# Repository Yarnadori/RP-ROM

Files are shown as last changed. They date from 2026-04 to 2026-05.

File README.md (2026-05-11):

# RP-ROM

M27C256 EPROM エミュレータ。RP2354A (RP2350 QFN-60) を搭載した自作 PCB で、32KB の ROM コンテンツを USB 経由で書き込み・読み出しできる。

## 概要

| 項目 | 内容 |
| --- | --- |
| 対象 EPROM | M27C256 互換 (32KB, 15-bit address, 8-bit data) |
| MCU | RP2354A (RP2350 QFN-60, 360 MHz 動作) |
| インターフェース | USB-C (CDC Serial) |
| フラッシュ保持 | 電源断後も ROM データを内蔵フラッシュに保存 |

## リポジトリ構成

```text
RP-ROM/
├── hardware/          # KiCad プロジェクト (回路図・PCB)
│   └── production/    # 製造用ファイル (BOM, Gerber, 部品配置)
├── software/          # RP2350 ファームウェア (C / Pico SDK)
│   └── main.c
└── tools/             # ホスト側 Python ツール
    └── rom_tool.py
```

## ハードウェア

KiCad で設計。製造 BOM の概要:

| Ref | 数量 | 部品 / 値 | パッケージ / 備考 | LCSC Part # |
| --- | ---: | --- | --- | --- |
| IC1 | 1 | RP2354A | QFN-60, メイン MCU | C41378174 |
| U1 | 1 | RT9080-33GJ5 | TSOT-23-5, 3.3V LDO | C7528830 |
| J1 | 1 | USB_C_Receptacle_USB2.0_16P | USB-C | C2843970 |
| J2, J3 | 2 | Conn_01x14_Pin | 1×14 ピンヘッダ | |
| J4 | 1 | Conn_01x03 | JST SH 3P, デバッガー | C7430452 |
| SW1 | 1 | SW_Push | TS-1088 系タクトスイッチ | C720477 |
| Y1 | 1 | 12 MHz | 3225 4-pin 水晶 | C9002 |
| L1 | 1 | 3.3uH | AOTA-B201610S3R3-101-T | C42411119 |
| D1, D2 | 2 | RB521S-30 | SOD-523 ショットキーダイオード | C8523 |
| D3 | 1 | LED | 0402 | C51933305 |
| C1 | 1 | 4.7nF | 0402 | C1538 |
| C2, C3 | 2 | 1uF | 0402 | C52923 |
| C5, C8 | 2 | 15pF | 0402 | C1548 |
| C9, C10, C11 | 3 | 4.7uF | 0402 | C23733 |
| C4, C6, C7, C12-C14 | 6 | 0.1uF | 0402 | C1525 |
| R1 | 1 | 1MΩ | 0402 | C26083 |
| R2, R3 | 2 | 5.1kΩ | 0402 | C25905 |
| R4, R5, R6 | 3 | 1k | 0402 | C11702 |
| R7, R8 | 2 | 27Ω | 0402 | C25100 |
| R9 | 1 | 33Ω | 0402 | C25105 |

製造ファイルは `hardware/production/` に格納。

## ファームウェア

### 必要環境

- [Raspberry Pi Pico SDK](https://github.com/raspberrypi/pico-sdk) v2.2.0

### 動作

- **Core 1**: ROM アドレス線監視・データ出力 (フラッシュ不使用のタイトループ、360 MHz)
- **Core 0**: USB シリアル経由のコマンド処理
- **永続化**: 書き込んだ ROM データを内蔵フラッシュ末尾 36KB に保存。電源投入時に自動ロード。

## ツール (tools/)

Python 製のホストツール。詳細は [tools/README.md](tools/README.md) を参照。

```bash
cd tools
uv run rom_tool.py write COM3 firmware.hex
uv run rom_tool.py read  COM3 dump.bin
uv run rom_tool.py verify COM3 firmware.hex
uv run rom_tool.py erase COM3
uv run rom_tool.py info  COM3
```

対応フォーマット: `.bin` / Intel HEX (`.hex`)

## ライセンス

[MIT License](LICENSE)

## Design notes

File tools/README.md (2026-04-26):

# RP-ROM Tools

RP-ROM EPROM エミュレータ用ホストツール。USB シリアル (CDC) 経由で ROM データの書き込み・読み出し・検証を行う。

## セットアップ

[uv](https://github.com/astral-sh/uv) を使用:

```bash
cd tools
uv sync
```

または pip:

```bash
pip install pyserial
```

## 使い方

```text
python rom_tool.py <command> <COMx> [file]
```

### コマンド一覧

| コマンド | 説明 |
| --- | --- |
| `write <port> <file>` | ROM イメージをデバイスに書き込む |
| `read <port> <file>` | デバイスから ROM イメージを読み出す |
| `verify <port> <file>` | デバイス内容をファイルと照合する |
| `erase <port>` | ROM を消去する (全バイト 0xFF) |
| `info <port>` | デバイス情報を表示する |

### 例

```bash
# .hex または .bin の書き込み
uv run rom_tool.py write COM3 firmware.hex
uv run rom_tool.py write COM3 firmware.bin

# 読み出し
uv run rom_tool.py read COM3 dump.bin
uv run rom_tool.py read COM3 dump.hex

# 書き込み後の検証
uv run rom_tool.py verify COM3 firmware.hex

# 消去
uv run rom_tool.py erase COM3

# デバイス情報
uv run rom_tool.py info COM3
```

## 対応ファイル形式

| 拡張子 | 形式 |
| --- | --- |
| `.hex` | Intel HEX |
| `.bin` / `.rom` / `.epr` | バイナリ |
| その他 | 先頭バイトで自動判別 |

ROM サイズ (32KB) に満たないバイナリは 0xFF でパディングされる。

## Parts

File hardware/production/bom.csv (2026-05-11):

Designator | Footprint | Quantity | Value | LCSC Part #
C1 | 0402 | 1 | 4.7nF | C1538
C10, C11, C9 | 0402 | 3 | 4.7u | C23733
C12, C13, C14, C4, C6, C7 | 0402 | 6 | 0.1u | C1525
C2, C3 | 0402 | 2 | 1uF | C52923
C5, C8 | 0402 | 2 | 15p | C1548
D1, D2 | D_SOD-523 | 2 | RB521S-30 | C8523
D3 | 0402 | 1 | LED | C51933305
IC1 | QFN-60-1EP_7x7mm_P0.4mm_EP3.4x3.4mm_ThermalVias | 1 | RP2354A | C41378174
J1 | USB_C_Receptacle_G-Switch_GT-USB-7051x | 1 | USB_C_Receptacle_USB2.0_16P | C2843970
J2, J3 | PinHeader_1x14_P2.54mm_Vertical | 2 | Conn_01x14_Pin
J4 | JST_SH_BM03B-SRSS-TB_1x03-1MP_P1.00mm_Vertical | 1 | Conn_01x03 | C7430452
L1 | AOTA-B201610S3R3-101-T | 1 | 3.3u | C42411119
R1 | 0402 | 1 | 1MΩ | C26083
R2, R3 | 0402 | 2 | 5.1kΩ | C25905
R4, R5, R6 | 0402 | 3 | 1k | C11702
R7, R8 | 0402 | 2 | 27 | C25100
R9 | 0402 | 1 | 33 | C25105
SW1 | SW_SPST_TS-1088-xR020 | 1 | SW_Push | C720477
U1 | TSOT-23-5 | 1 | RT9080-33GJ5 | C7528830
Y1 | Crystal_SMD_3225-4Pin_3.2x2.5mm | 1 | 12m | C9002

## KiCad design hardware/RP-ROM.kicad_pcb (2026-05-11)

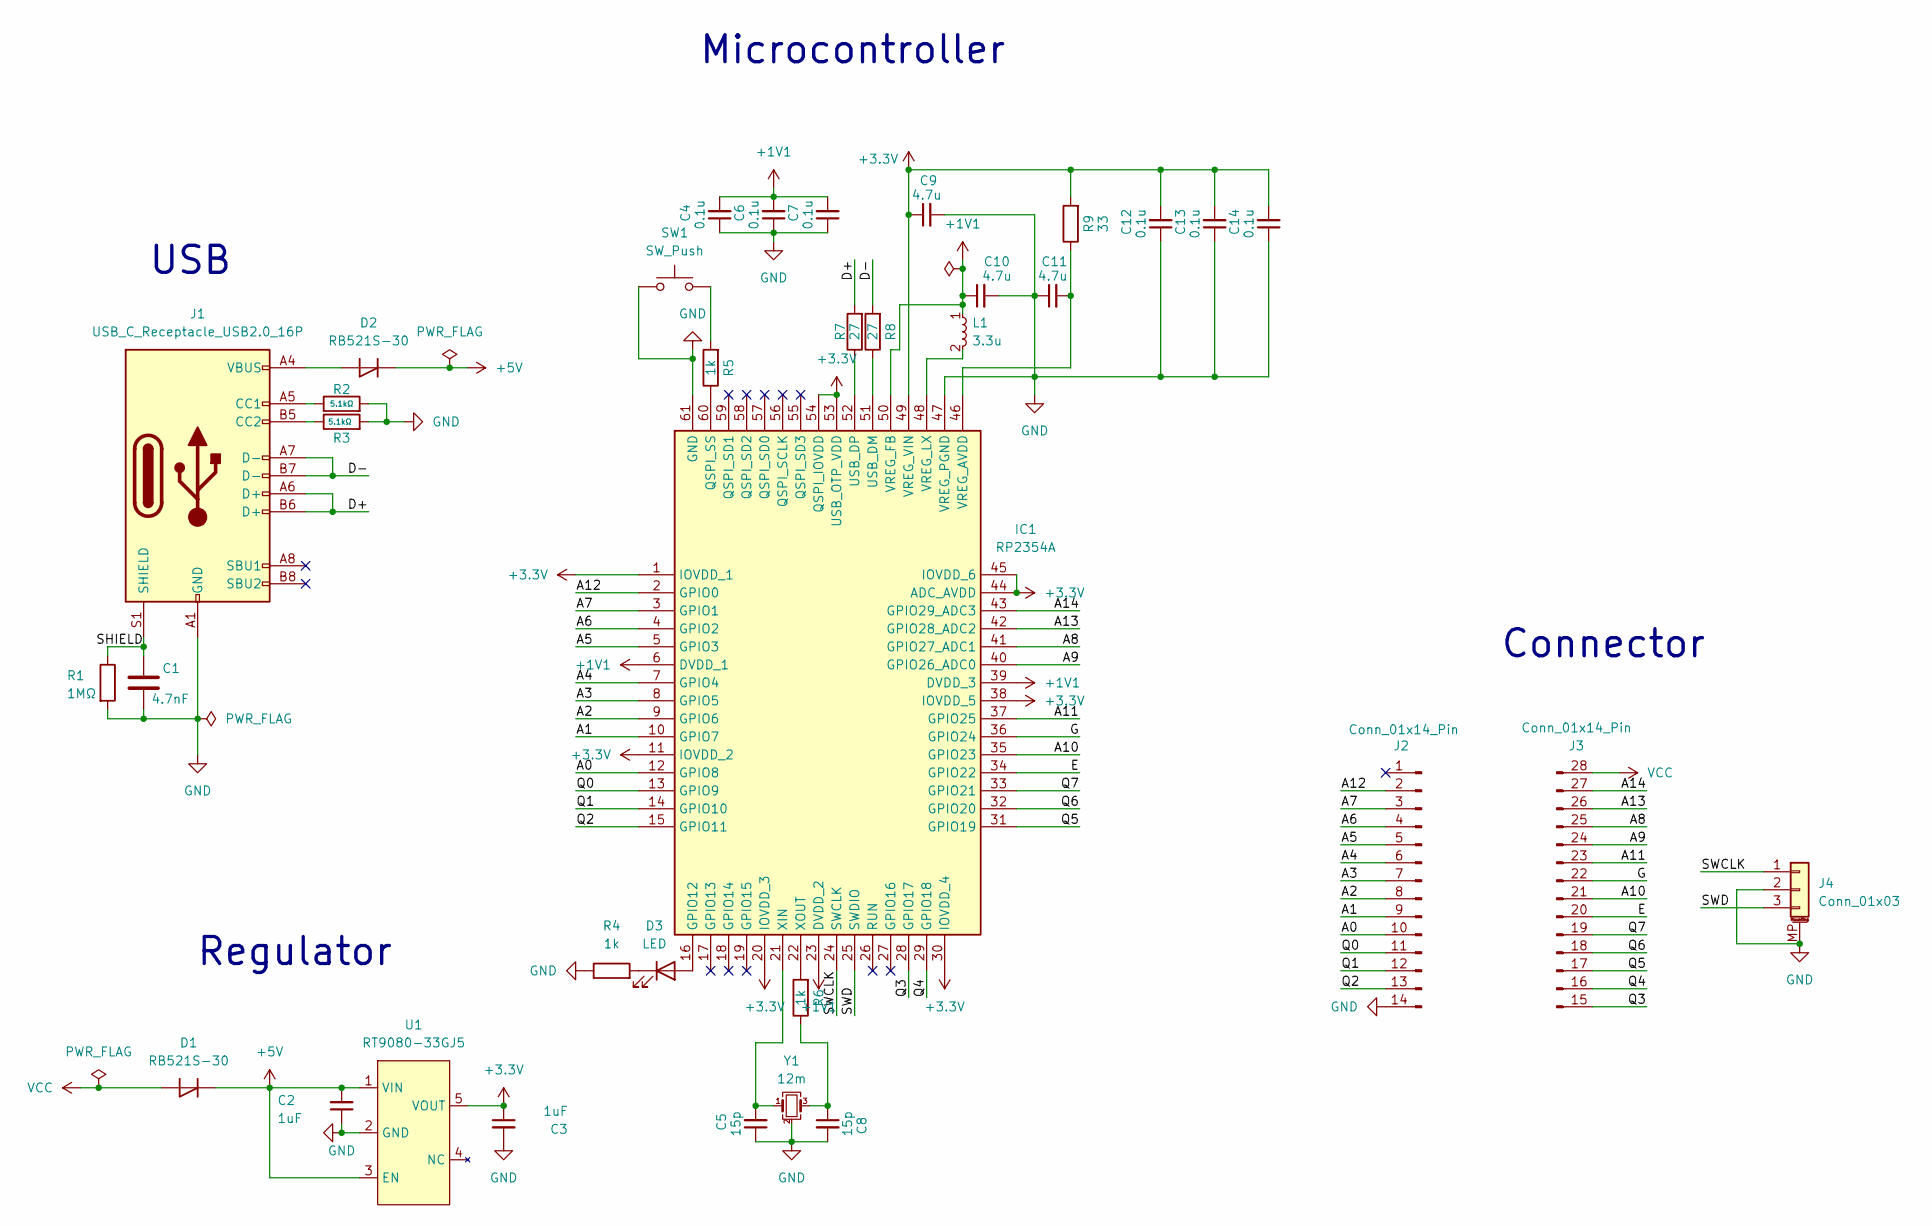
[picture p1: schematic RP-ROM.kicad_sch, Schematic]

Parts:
C1: 4.7nF; C_0402_1005Metric; JLCPCB Part # C1538
C2, C3: 1uF; C_0402_1005Metric; JLCPCB Part # C52923
C4, C6, C7, C12, C13, C14: 0.1u; C_0402_1005Metric; JLCPCB Part # C1525
C5, C8: 15p; C_0402_1005Metric; JLCPCB Part # C1548
C9, C10, C11: 4.7u; C_0402_1005Metric; JLCPCB Part # C23733
D1, D2: RB521S-30; D_SOD-523; JLCPCB Part # C8523
D3: LED; LED_0402_1005Metric; JLCPCB Part # C51933305
IC1: RP2354A; QFN-60-1EP_7x7mm_P0.4mm_EP3.4x3.4mm_ThermalVias; Manufacturer_Part_Number RP2354A; JLCPCB Part # C41378174
J1: USB_C_Receptacle_USB2.0_16P; USB_C_Receptacle_G-Switch_GT-USB-7051x; JLCPCB Part # C2843970
J2, J3: Conn_01x14_Pin; PinHeader_1x14_P2.54mm_Vertical
J4: Conn_01x03; JST_SH_BM03B-SRSS-TB_1x03-1MP_P1.00mm_Vertical; JLCPCB Part # C7430452
L1: 3.3u; AOTA-B201610S3R3-101-T; JLCPCB Part # C42411119
R1: 1MΩ; R_0402_1005Metric; JLCPCB Part # C26083
R2, R3: 5.1kΩ; R_0402_1005Metric; JLCPCB Part # C25905
R4, R5, R6: 1k; R_0402_1005Metric; JLCPCB Part # C11702
R7, R8: 27; R_0402_1005Metric; JLCPCB Part # C25100
R9: 33; R_0402_1005Metric; JLCPCB Part # C25105
SW1: SW_Push; SW_SPST_TS-1088-xR020; JLCPCB Part # C720477
U1: RT9080-33GJ5; TSOT-23-5; JLCPCB Part # C7528830
Y1: 12m; Crystal_SMD_3225-4Pin_3.2x2.5mm; JLCPCB Part # C9002

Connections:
+1V1: C4.2, C6.2, C7.2, C10.1, IC1.6 (DVDD_1), IC1.23 (DVDD_2), IC1.39 (DVDD_3), IC1.50 (VREG_FB), L1.1
+3.3V: C3.1, C9.1, C12.2, C13.2, C14.2, IC1.1 (IOVDD_1), IC1.11 (IOVDD_2), IC1.20 (IOVDD_3), IC1.30 (IOVDD_4), IC1.38 (IOVDD_5), IC1.44 (ADC_AVDD), IC1.45 (IOVDD_6), IC1.49 (VREG_VIN), IC1.53 (USB_OTP_VDD), IC1.54 (QSPI_IOVDD), R9.2, U1.5 (VOUT)
+5V: C2.2, D1.1 (K), D2.1 (K), U1.1 (VIN), U1.3 (EN)
/A0: IC1.12 (GPIO8), J2.10
/A1: IC1.10 (GPIO7), J2.9
/A2: IC1.9 (GPIO6), J2.8
/A3: IC1.8 (GPIO5), J2.7
/A4: IC1.7 (GPIO4), J2.6
/A5: IC1.5 (GPIO3), J2.5
/A6: IC1.4 (GPIO2), J2.4
/A7: IC1.3 (GPIO1), J2.3
/A8: IC1.41 (GPIO27_ADC1), J3.25 (Pin_11)
/A9: IC1.40 (GPIO26_ADC0), J3.24 (Pin_10)
/A10: IC1.35 (GPIO23), J3.21 (Pin_7)
/A11: IC1.37 (GPIO25), J3.23 (Pin_9)
/A12: IC1.2 (GPIO0), J2.2
/A13: IC1.42 (GPIO28_ADC2), J3.26 (Pin_12)
/A14: IC1.43 (GPIO29_ADC3), J3.27 (Pin_13)
/D+: J1.A6 (D+), J1.B6 (D+), R7.2
/D-: J1.A7 (D-), J1.B7 (D-), R8.2
/E: IC1.34 (GPIO22), J3.20 (Pin_6)
/G: IC1.36 (GPIO24), J3.22 (Pin_8)
/Q0: IC1.13 (GPIO9), J2.11
/Q1: IC1.14 (GPIO10), J2.12
/Q2: IC1.15 (GPIO11), J2.13
/Q3: IC1.28 (GPIO17), J3.15 (Pin_1)
/Q4: IC1.29 (GPIO18), J3.16 (Pin_2)
/Q5: IC1.31 (GPIO19), J3.17 (Pin_3)
/Q6: IC1.32 (GPIO20), J3.18 (Pin_4)
/Q7: IC1.33 (GPIO21), J3.19 (Pin_5)
/SHIELD: C1.1, J1.S1 (SHIELD), R1.1
/SWCLK: IC1.24 (SWCLK), J4.1
/SWD: IC1.25 (SWDIO), J4.3
GND: C1.2, C2.1, C3.2, C4.1, C5.1, C6.1, C7.1, C8.2, C9.2, C10.2, C11.1, C12.1, C13.1, C14.1, IC1.47 (VREG_PGND), IC1.61 (GND), J1.A1 (GND), J1.A12 (GND), J1.B1 (GND), J1.B12 (GND), J2.14, J4.2, J4.MP (MountPin), R1.2, R2.2, R3.2, R4.1, SW1.1, U1.2 (GND), Y1.2 (G), Y1.4 (G)
unnamed: C8.1, R6.1, Y1.3
unnamed: D2.2 (A), J1.A4 (VBUS), J1.A9 (VBUS), J1.B4 (VBUS), J1.B9 (VBUS)
unnamed: D3.2 (A), IC1.16 (GPIO12)
unnamed: D3.1 (K), R4.2
unnamed: IC1.60 (QSPI_SS), R5.1
unnamed: IC1.51 (USB_DM), R8.1
unnamed: IC1.52 (USB_DP), R7.1
unnamed: C11.2, IC1.46 (VREG_AVDD), R9.1
unnamed: IC1.48 (VREG_LX), L1.2
unnamed: C5.2, IC1.21 (XIN), Y1.1
unnamed: IC1.22 (XOUT), R6.2
unnamed: J1.A5 (CC1), R2.1
unnamed: J1.B5 (CC2), R3.1
unnamed: R5.2, SW1.2
VCC: D1.2 (A), J3.28 (Pin_14)

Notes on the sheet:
Connector
Regulator
Microcontroller
USB

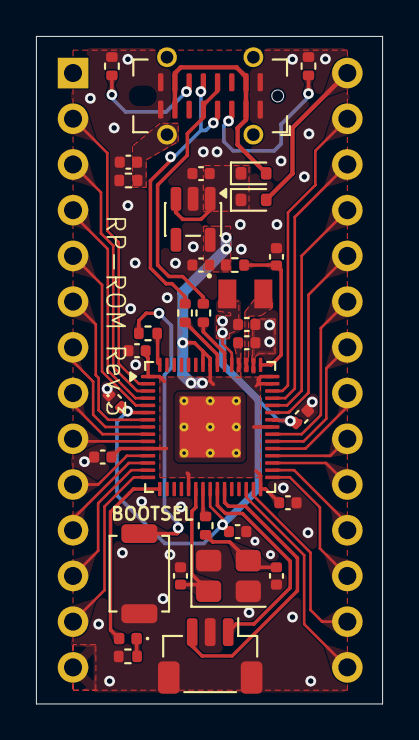
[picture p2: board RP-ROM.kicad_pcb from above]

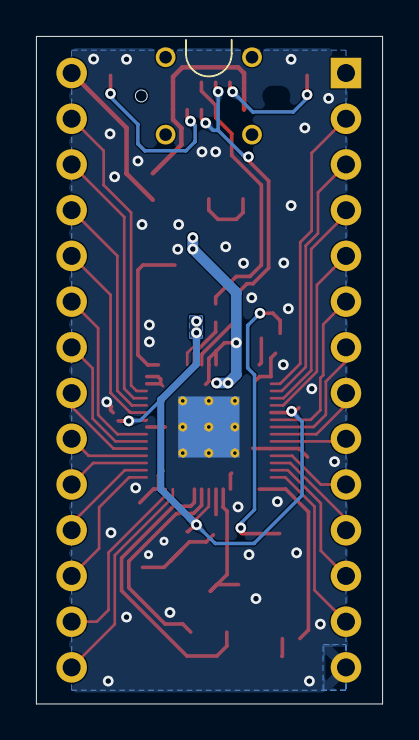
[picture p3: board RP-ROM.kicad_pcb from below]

Board: 2 copper layers, 19.2 x 37.1 mm, 35 parts (2 on the bottom side), 49 nets.

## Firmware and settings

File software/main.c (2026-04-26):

#include <stdio.h>
#include <string.h>
#include "pico/stdlib.h"
#include "pico/multicore.h"
#include "hardware/vreg.h"
#include "hardware/clocks.h"
#include "hardware/flash.h"
#include "hardware/sync.h"
#include "hardware/structs/sio.h"

#define PIN_A0 8
#define PIN_A1 7
#define PIN_A2 6
#define PIN_A3 5
#define PIN_A4 4
#define PIN_A5 3
#define PIN_A6 2
#define PIN_A7 1
#define PIN_A8 27
#define PIN_A9 26
#define PIN_A10 23
#define PIN_A11 25
#define PIN_A12 0
#define PIN_A13 28
#define PIN_A14 29

#define PIN_D0 9
#define PIN_D1 10
#define PIN_D2 11
#define PIN_D3 17
#define PIN_D4 18
#define PIN_D5 19
#define PIN_D6 20
#define PIN_D7 21

#define PIN_CE_N 24 // active low, labeled G on schematic
#define PIN_OE_N 22 // active low, labeled E on schematic
#define PIN_LED 12

#define ROM_SIZE (32u * 1024u) // M27C256 = 32KB

// Flash tail 36KB: first 4KB for metadata, remaining 32KB for ROM data
#define FLASH_RESERVED_SIZE  (9u * FLASH_SECTOR_SIZE)
#define FLASH_META_OFFSET    (PICO_FLASH_SIZE_BYTES - FLASH_RESERVED_SIZE)
#define FLASH_ROM_OFFSET     (FLASH_META_OFFSET + FLASH_SECTOR_SIZE)
#define FLASH_META_ADDR      (XIP_BASE + FLASH_META_OFFSET)
#define FLASH_ROM_ADDR       (XIP_BASE + FLASH_ROM_OFFSET)
#define FLASH_MAGIC          0x52504F4Du // 'RPOM'

#define DATA_PIN_MASK ((1u << PIN_D0) | (1u << PIN_D1) | (1u << PIN_D2) | (1u << PIN_D3) | (1u << PIN_D4) | (1u << PIN_D5) | (1u << PIN_D6) | (1u << PIN_D7))

static uint8_t rom_data[ROM_SIZE];
static volatile bool rom_updating = false;
static volatile bool core1_paused = false;

// gpio_lo_lut[i]: i = GPIO[8:0] (9-bit), result = partial address from A0,A1-A7,A12
//   GPIO0=A12, GPIO1=A7, GPIO2=A6, GPIO3=A5, GPIO4=A4, GPIO5=A3, GPIO6=A2, GPIO7=A1, GPIO8=A0
// GPIO8(A0) is folded in to eliminate the separate | ((g>>8)&1) op in the hot loop
static uint16_t gpio_lo_lut[512];

// gpio_hi_lut[i]: i = GPIO[29:23] packed into 7 bits, result = partial address from A8-A14
//   bit0(GPIO23)=A10, bit1(GPIO24)=CE#(skip), bit2(GPIO25)=A11,
//   bit3(GPIO26)=A9,  bit4(GPIO27)=A8, bit5(GPIO28)=A13, bit6(GPIO29)=A14
static uint16_t gpio_hi_lut[128];

// addr_out_lut[addr]: combines rom_data lookup and data pin mapping into one SRAM access.
// 32KB * 4B = 128KB; total SRAM use stays well within 264KB.
static uint32_t addr_out_lut[ROM_SIZE];

// byte value -> GPIO bitmask for data pins; used only during LUT rebuild
static uint32_t data_out_lut[256];

static void build_luts(void)
{
    for (int i = 0; i < 512; i++)
    {
        uint16_t a = 0;
        a |= (uint16_t)(((i >> 0) & 1) << 12); // GPIO0 -> A12
        a |= (uint16_t)(((i >> 1) & 1) << 7);  // GPIO1 -> A7
        a |= (uint16_t)(((i >> 2) & 1) << 6);  // GPIO2 -> A6
        a |= (uint16_t)(((i >> 3) & 1) << 5);  // GPIO3 -> A5
        a |= (uint16_t)(((i >> 4) & 1) << 4);  // GPIO4 -> A4
        a |= (uint16_t)(((i >> 5) & 1) << 3);  // GPIO5 -> A3
        a |= (uint16_t)(((i >> 6) & 1) << 2);  // GPIO6 -> A2
        a |= (uint16_t)(((i >> 7) & 1) << 1);  // GPIO7 -> A1
        a |= (uint16_t)(((i >> 8) & 1) << 0);  // GPIO8 -> A0
        gpio_lo_lut[i] = a;
    }
    for (int i = 0; i < 128; i++)
    {
        uint16_t a = 0;
        a |= (uint16_t)(((i >> 0) & 1) << 10); // bit0 (GPIO23) -> A10
        // bit1 (GPIO24) = CE#, skip
        a |= (uint16_t)(((i >> 2) & 1) << 11); // bit2 (GPIO25) -> A11
        a |= (uint16_t)(((i >> 3) & 1) << 9);  // bit3 (GPIO26) -> A9
        a |= (uint16_t)(((i >> 4) & 1) << 8);  // bit4 (GPIO27) -> A8
        a |= (uint16_t)(((i >> 5) & 1) << 13); // bit5 (GPIO28) -> A13
        a |= (uint16_t)(((i >> 6) & 1) << 14); // bit6 (GPIO29) -> A14
        gpio_hi_lut[i] = a;
    }
    for (int i = 0; i < 256; i++)
    {
        uint32_t m = 0;
        m |= (uint32_t)(((i >> 0) & 1) << PIN_D0);
        m |= (uint32_t)(((i >> 1) & 1) << PIN_D1);
        m |= (uint32_t)(((i >> 2) & 1) << PIN_D2);
        m |= (uint32_t)(((i >> 3) & 1) << PIN_D3);
        m |= (uint32_t)(((i >> 4) & 1) << PIN_D4);
        m |= (uint32_t)(((i >> 5) & 1) << PIN_D5);
        m |= (uint32_t)(((i >> 6) & 1) << PIN_D6);
        m |= (uint32_t)(((i >> 7) & 1) << PIN_D7);
        data_out_lut[i] = m;
    }
}

// Call whenever rom_data changes.
static void build_addr_out_lut(void)
{
    for (uint32_t i = 0; i < ROM_SIZE; i++)
        addr_out_lut[i] = data_out_lut[rom_data[i]];
}

// Runs from SRAM; gpio_lo_lut covers GPIO[8:0] so A0 is already included.
static inline uint16_t __not_in_flash_func(gpio_to_addr)(uint32_t g)
{
    return (uint16_t)(gpio_lo_lut[g & 0x1FFu] | gpio_hi_lut[(g >> 23) & 0x7Fu]);
}

// Core 1 ROM emulation tight loop (executes from SRAM)
static void __not_in_flash_func(rom_emulator_core1)(void)
{
    const uint32_t CE_MASK = (1u << PIN_CE_N);
    const uint32_t OE_MASK = (1u << PIN_OE_N);
    const uint32_t ACTIVE_MASK = CE_MASK | OE_MASK;

    while (true)
    {
        if (rom_updating)
        {
            sio_hw->gpio_oe_clr = DATA_PIN_MASK;
            core1_paused = true;
            while (rom_updating)
                tight_loop_contents();
            core1_paused = false;
            __dmb(); // acquire barrier: ensure fresh rom_data[] / addr_out_lut[] visible
        }

        // address is already stable when CE# asserts
        while (sio_hw->gpio_in & CE_MASK)
            tight_loop_contents();

        // capture GPIO snapshot atomically when OE# asserts
        uint32_t g;
        while ((g = sio_hw->gpio_in) & OE_MASK)
            tight_loop_contents();

        uint32_t out = addr_out_lut[gpio_to_addr(g)];
        sio_hw->gpio_set = out;
        sio_hw->gpio_clr = DATA_PIN_MASK ^ out; // out ⊆ DATA_PIN_MASK so XOR = AND NOT
        sio_hw->gpio_oe_set = DATA_PIN_MASK;

        while (!(sio_hw->gpio_in & ACTIVE_MASK))
            tight_loop_contents();

        sio_hw->gpio_oe_clr = DATA_PIN_MASK;
    }
}

// Runs from SRAM; Core 1 must be paused beforehand.
static void __not_in_flash_func(flash_save_rom)(void)
{
    while (!core1_paused)
        tight_loop_contents();

    uint32_t ints = save_and_disable_interrupts();

    flash_range_erase(FLASH_META_OFFSET, FLASH_RESERVED_SIZE);

    uint8_t meta[FLASH_PAGE_SIZE];
    memset(meta, 0xFF, sizeof(meta));
    *(uint32_t *)meta = FLASH_MAGIC;
    flash_range_program(FLASH_META_OFFSET, meta, FLASH_PAGE_SIZE);

    flash_range_program(FLASH_ROM_OFFSET, rom_data, ROM_SIZE);

    restore_interrupts(ints);
}

// Commands (single byte): W=write 32768 bytes, R=read 32768 bytes, E=erase (fill 0xFF), I=info
static void __not_in_flash_func(handle_usb)(void)
{
    int c = getchar_timeout_us(0);
    if (c == PICO_ERROR_TIMEOUT)
        return;

    if (c == 'W')
    {
        rom_updating = true;
        __dmb();

        bool ok = true;
        for (uint32_t i = 0; i < ROM_SIZE; i++)
        {
            int b = PICO_ERROR_TIMEOUT;
            for (int retry = 0; retry < 10 && b == PICO_ERROR_TIMEOUT; retry++)
                b = getchar_timeout_us(500000);
            if (b == PICO_ERROR_TIMEOUT)
            {
                ok = false;
                break;
            }
            rom_data[i] = (uint8_t)b;
        }
        if (ok)
        {
            build_addr_out_lut();
            flash_save_rom();
        }

        __dmb();
        rom_updating = false;

        putchar_raw(ok ? 'K' : 'X');
    }
    else if (c == 'R')
    {
        for (uint32_t i = 0; i < ROM_SIZE; i++)
            putchar_raw(rom_data[i]);
    }
    else if (c == 'E')
    {
        rom_updating = true;
        __dmb();
        memset(rom_data, 0xFF, ROM_SIZE);
        build_addr_out_lut();
        __dmb();
        rom_updating = false;
        putchar_raw('K');
    }
    else if (c == 'I')
    {
        printf("RP-ROM EPROM Emulator (M27C256 compatible)\r\n");
        printf("Clock : %lu Hz\r\n", (unsigned long)clock_get_hz(clk_sys));
        printf("ROM   : %u bytes\r\n", ROM_SIZE);
        printf("Cmds  : W=write R=read E=erase I=info\r\n");
    }
}

static void setup_gpio(void)
{
    const uint addr_pins[] = {
        PIN_A0, PIN_A1, PIN_A2, PIN_A3, PIN_A4, PIN_A5, PIN_A6, PIN_A7,
        PIN_A8, PIN_A9, PIN_A10, PIN_A11, PIN_A12, PIN_A13, PIN_A14};
    for (int i = 0; i < 15; i++)
    {
        gpio_init(addr_pins[i]);
        gpio_set_dir(addr_pins[i], GPIO_IN);
        gpio_disable_pulls(addr_pins[i]);
    }

    gpio_init(PIN_CE_N);
    gpio_set_dir(PIN_CE_N, GPIO_IN);
    gpio_disable_pulls(PIN_CE_N);
    gpio_init(PIN_OE_N);
    gpio_set_dir(PIN_OE_N, GPIO_IN);
    gpio_disable_pulls(PIN_OE_N);

    const uint data_pins[] = {
        PIN_D0, PIN_D1, PIN_D2, PIN_D3, PIN_D4, PIN_D5, PIN_D6, PIN_D7};
    for (int i = 0; i < 8; i++)
    {
        gpio_init(data_pins[i]);
        gpio_set_dir(data_pins[i], GPIO_IN);
        gpio_disable_pulls(data_pins[i]);
    }

    gpio_init(PIN_LED);
    gpio_set_dir(PIN_LED, GPIO_OUT);
    gpio_put(PIN_LED, 0);
}

int main(void)
{
    vreg_set_voltage(VREG_VOLTAGE_1_30);
    sleep_ms(10);
    set_sys_clock_khz(360000, true);
    sleep_ms(10);

    stdio_init_all();

    if (*(const uint32_t *)FLASH_META_ADDR == FLASH_MAGIC)
        memcpy(rom_data, (const uint8_t *)FLASH_ROM_ADDR, ROM_SIZE);
    else
        memset(rom_data, 0xFF, ROM_SIZE);

    build_luts();
    build_addr_out_lut();
    setup_gpio();

    multicore_launch_core1(rom_emulator_core1);

    gpio_put(PIN_LED, 1);

    while (true)
    {
        handle_usb();
    }
}

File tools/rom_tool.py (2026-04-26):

import sys
import argparse
import struct

ROM_SIZE = 32 * 1024  # 32KB (M27C256)


# ---- File loaders ----


def load_bin(path: str) -> bytes:
    with open(path, "rb") as f:
        data = f.read()
    if len(data) > ROM_SIZE:
        raise ValueError(
            f"File is {len(data)} bytes, exceeds ROM size ({ROM_SIZE} bytes)"
        )
    if len(data) < ROM_SIZE:
        print(f"  Padding {ROM_SIZE - len(data)} bytes with 0xFF")
        data = data + b"\xff" * (ROM_SIZE - len(data))
    return data


def load_hex(path: str) -> bytes:
    rom = bytearray(b"\xff" * ROM_SIZE)
    base = 0
    with open(path, "r") as f:
        for lineno, line in enumerate(f, 1):
            line = line.strip()
            if not line.startswith(":"):
                continue
            raw = bytes.fromhex(line[1:])
            if sum(raw) & 0xFF != 0:
                raise ValueError(f"Checksum error at line {lineno}")
            byte_count = raw[0]
            address = struct.unpack_from(">H", raw, 1)[0]
            rec_type = raw[3]
            payload = raw[4 : 4 + byte_count]

            if rec_type == 0x00:  # Data
                addr = base + address
                if addr + byte_count > ROM_SIZE:
                    raise ValueError(
                        f"Data at 0x{addr:04X}+{byte_count} exceeds ROM size at line {lineno}"
                    )
                rom[addr : addr + byte_count] = payload
            elif rec_type == 0x01:  # End Of File
                break
            elif rec_type == 0x02:  # Extended Segment Address
                base = struct.unpack_from(">H", payload)[0] << 4
            elif rec_type == 0x04:  # Extended Linear Address
                base = struct.unpack_from(">H", payload)[0] << 16
            elif rec_type in (0x03, 0x05):  # Start address records - ignore
                pass
            else:
                raise ValueError(
                    f"Unknown record type 0x{rec_type:02X} at line {lineno}"
                )
    return bytes(rom)


def detect_and_load(path: str) -> bytes:
    ext = path.lower().rsplit(".", 1)[-1] if "." in path else ""
    if ext == "hex":
        print("  Format: Intel HEX")
        return load_hex(path)
    elif ext in ("bin", "rom", "epr"):
        print("  Format: Binary")
        return load_bin(path)
    else:
        with open(path, "rb") as f:
            sig = f.read(1)
        if sig == b":":
            print("  Format: Intel HEX (detected by content)")
            return load_hex(path)
        else:
            print("  Format: Binary (detected by content)")
            return load_bin(path)


# ---- File savers ----


def save_hex(path: str, data: bytes) -> None:
    RECORD_LEN = 16
    lines = []
    for addr in range(0, len(data), RECORD_LEN):
        chunk = data[addr : addr + RECORD_LEN]
        if all(b == 0xFF for b in chunk):  # skip erased (0xFF) regions
            continue
        n = len(chunk)
        record = bytes([n, (addr >> 8) & 0xFF, addr & 0xFF, 0x00]) + chunk
        checksum = (-sum(record)) & 0xFF
        lines.append(f":{record.hex().upper()}{checksum:02X}")
    lines.append(":00000001FF")  # EOF record
    with open(path, "w") as f:
        f.write("\n".join(lines) + "\n")


def save_file(path: str, data: bytes) -> None:
    ext = path.lower().rsplit(".", 1)[-1] if "." in path else ""
    if ext == "hex":
        print("  Format: Intel HEX")
        save_hex(path, data)
    else:
        print("  Format: Binary")
        with open(path, "wb") as f:
            f.write(data)


# ---- Serial helpers ----


def open_port(port: str):
    try:
        import serial
    except ImportError:
        print("Error: pyserial not installed. Run: pip install pyserial")
        sys.exit(1)
    return serial.Serial(port, baudrate=115200, timeout=10)


# ---- Commands ----


def cmd_write(args):
    print(f"[Write]  Port: {args.port}  File: {args.file}")
    data = detect_and_load(args.file)
    assert len(data) == ROM_SIZE

    with open_port(args.port) as ser:
        ser.reset_input_buffer()
        print("  Sending 'W' command ...")
        ser.write(b"W")

        print(f"  Writing {ROM_SIZE} bytes", end="", flush=True)
        chunk = 256
        for i in range(0, ROM_SIZE, chunk):
            ser.write(data[i : i + chunk])
            if (i // chunk) % 32 == 31:
                print(".", end="", flush=True)
        print()

        print("  Waiting for ACK ...")
        ack = ser.read(1)
        if ack == b"K":
            print("  Done: Write successful.")
        elif ack == b"X":
            print("  Error: Device reported timeout/abort.")
            sys.exit(1)
        else:
            print(f"  Error: Unexpected response: {(ack + ser.read(64))!r}")
            sys.exit(1)


def cmd_read(args):
    print(f"[Read]  Port: {args.port}  Output: {args.file}")
    print(f"  Reading {ROM_SIZE} bytes", end="", flush=True)

    with open_port(args.port) as ser:
        try:
            data = do_read(ser)
        except IOError as e:
            print(f"  Error: {e}")
            sys.exit(1)

    save_file(args.file, data)
    print(f"  Done: {ROM_SIZE} bytes saved to {args.file}")


def do_read(ser) -> bytes:
    ser.reset_input_buffer()
    ser.write(b"R")
    data = bytearray()
    while len(data) < ROM_SIZE:
        chunk = ser.read(ROM_SIZE - len(data))
        if not chunk:
            raise IOError(f"Timeout after {len(data)} bytes.")
        data.extend(chunk)
        dots = len(data) // (ROM_SIZE // 32)
        print(
            "\r  Reading %d bytes  %s" % (len(data), "." * dots),
            end="",
            flush=True,
        )
    print()
    return bytes(data)


def print_diff(expected: bytes, actual: bytes) -> int:
    diffs = [
        (i, expected[i], actual[i])
        for i in range(ROM_SIZE)
        if expected[i] != actual[i]
    ]
    if not diffs:
        return 0
    print(f"  {len(diffs)} byte(s) differ:")
    for addr, exp, got in diffs[:32]:
        print(f"    0x{addr:04X}: expected 0x{exp:02X}, got 0x{got:02X}")
    if len(diffs) > 32:
        print(f"    ... and {len(diffs) - 32} more")
    # Check if it looks like a systematic offset
    offsets = [
        got - exp for _, exp, got in diffs if exp != 0xFF and got != 0xFF
    ]
    if offsets and len(set(offsets)) == 1:
        print(
            f"  Hint: all differences are a constant offset of {offsets[0]:+d} -- possible address shift?"
        )
    return len(diffs)


def cmd_verify(args):
    print(f"[Verify]  Port: {args.port}  File: {args.file}")
    expected = detect_and_load(args.file)

    with open_port(args.port) as ser:
        actual = do_read(ser)

    n = print_diff(expected, actual)
    if n == 0:
        print("  OK: Device content matches file exactly.")
    else:
        print(f"  FAIL: {n} byte(s) differ.")
        sys.exit(1)
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
